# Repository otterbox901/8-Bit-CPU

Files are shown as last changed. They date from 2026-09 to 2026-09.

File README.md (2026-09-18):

# 8-Bit CPU

A CPU built from ~97 individual 74HC-series logic ICs. Custom instruction set, microcoded control unit, and a from-scratch ALU with flag logic, laid out on a 4-layer PCB.

## Status: In progress

- [x] Instruction set architecture (11 instructions, custom encoding)
- [x] ALU design — adder/subtractor, bitwise AND/OR, Z/C/N flag generation
- [x] Register file (4 general-purpose registers) and microcoded control-ROM addressing scheme
- [x] PCB component placement — 97 ICs, board outline drawn (173.5 mm × 115.5 mm, 4-layer)
- [x] Microcode ROM generator — Python script producing control-ROM contents from the ISA/microcode design, checked against the control-unit addressing scheme
- [x] Emulator — Python simulator + assembler that executes `microcode_table.csv` directly, with the full ISA exercised by a bundled test program
- [x] Control unit — the schematic's control-ROM addressing, register-file/ALU
      enable logic, and memory control signals are now actually wired
- [x] PCB routing — fully autorouted (4-layer, 755 nets, 0 DRC errors)
- [ ] Power input connector + regulator (not yet designed — see Known Issues)
- [ ] HLT (clock/sequencer halt) — control-ROM signal exists but isn't wired
      to anything yet
- [ ] Burn control ROM onto physical EEPROMs and hardware bring-up

## Overview

| | |
|---|---|
| Data path | 8-bit |
| Registers | 4 general-purpose (R0–R3), plus PC, MAR, IR, and internal ALU staging registers |
| Control unit | Microcoded — control ROM addressed by opcode, execution step, and ALU status flags (no hardwired branch/decision logic) |
| ALU | Add, subtract (two's complement), AND, OR — with Zero, Carry, and Negative flags |
| Memory | Harvard-style — separate address space for program storage (EEPROM) and data storage (SRAM) |
| Clock target | 1–4 MHz |
| Logic family | 74HC/74LS discrete logic |
| IC count | ~97 |
| Board | 4-layer, 1.6 mm, 173.5 mm × 115.5 mm |

## Instruction Set

| Opcode | Mnemonic | Format | Operation |
|---|---|---|---|
| `0000` | `NOP` | — | No operation |
| `0001` | `LOAD Rd, addr` | Address (3 bytes) | Rd ← MEM[addr] |
| `0010` | `STORE Rd, addr` | Address (3 bytes) | MEM[addr] ← Rd |
| `0011` | `ADD Rd, Rs` | Reg-reg (1 byte) | Rd ← Rd + Rs |
| `0100` | `SUB Rd, Rs` | Reg-reg (1 byte) | Rd ← Rd − Rs |
| `0101` | `JMP addr` | Address (3 bytes) | PC ← addr |
| `0110` | `JZ addr` | Address (3 bytes) | PC ← addr if Zero flag set |
| `0111` | `JC addr` | Address (3 bytes) | PC ← addr if Carry flag set |
| `1000` | `MOV Rd, Rs` | Reg-reg (1 byte) | Rd ← Rs |
| `1001` | `AND Rd, Rs` | Reg-reg (1 byte) | Rd ← Rd AND Rs |
| `1010` | `OR Rd, Rs` | Reg-reg (1 byte) | Rd ← Rd OR Rs |
| `1111` | `HLT` | — | Stop the clock |

Opcodes `1011`–`1110` are reserved for future extension (e.g. a stack pointer with `CALL`/`RET`, or additional ALU operations). Currently they fetch and decode as a no-op.

Instructions are encoded as either one byte (reg-reg) or three bytes (address):

| Format | Byte 0 | Byte 1 | Byte 2 |
|---|---|---|---|
| Reg-reg | `[opcode:4][Rd:2][Rs:2]` | — | — |
| Address | `[opcode:4][Rd:2][--:2]` | addr low | addr high |

The 3-bit step counter cycles 0–7 (wrapping); step 0 is always the fetch (`IROM_OUT` + `IR_IN` + `PC_INC`), steps 1–3 execute the operand/operation, and any trailing steps are no-ops. Conditional jumps are resolved entirely by the control ROM's addressing (the flag bits are part of the ROM address), with no separate comparator logic needed.

## Control ROM

The control ROM is generated rather than hand-populated. A Python script (`microcode_rom_gen.py`) walks every `(opcode, step, Z, C)` combination — a 9-bit, 512-word address space, and derives the 20-bit control word for each from the microcode step tables for each instruction. The control word is split across three 28C256 EEPROMs (8 + 8 + 4 bits), and the script emits both a human-readable CSV (`microcode_table.csv`) and three raw 32 KB binary chip images (`rom1.bin`, `rom2.bin`, `rom3.bin`) ready to burn, with unused upper addresses zero-padded to an all-signals-off state.

## Emulator

`emulator.py` is a cycle-accurate Python model of the CPU driven entirely by the generated control ROM. It arbitrates the 8-bit bus, latches registers and flags per the microcode control signals, and assembles + runs programs, so it can be used to develop and verify software before the hardware comes up.

### Usage

```bash
# Generate the control ROM table first (run from ROM/)
python3 microcode_rom_gen.py

# Run the full instruction-set test program (7/7 checks pass)
python3 emulator.py test_program.asm

# Run the bundled default test (no file argument)
python3 emulator.py

# Per-micro-step trace of bus, registers, and control signals
python3 emulator.py test_program.asm --trace-micro

# Quiet mode — suppress trace, show results only
python3 emulator.py -q test_program.asm
```

The built-in two-pass assembler understands the instruction mnemonics, labels, hex/decimal numbers, `.byte` (program ROM data) and `.ram addr, val` (pre-loads the data SRAM) directives. `test_program.asm` exercises every instruction — LOAD, STORE, ADD, SUB, AND, OR, MOV, NOP, JMP, JZ, JC, HLT — and auto-verifies the resulting data RAM contents against expected values.

## Repo Contents

```
8-Bit-CPU/
├── 8-bit cpu.kicad_sch     KiCad schematic (single flat sheet)
├── 8-bit cpu.kicad_pcb     KiCad PCB layout (routed, 0 DRC errors)
├── microcode_rom_gen.py    Control ROM generator (opcode/step/flags → EEPROM images)
├── emulator.py             Microcode-driven CPU emulator + assembler
├── test_program.asm        Full instruction-set test for the emulator
└── README.md
```

## Known Issues

- **No power input connector or regulator.** All 63 live ICs now share a
  single, correctly-named `+5V` net, but nothing in the schematic actually
  sources it — there's no barrel jack/header and no regulator IC modeled.
  This needs to be designed and added before the board can be powered.
- **HLT isn't wired to anything.** The control ROM correctly asserts the
  `HLT` signal per the microcode, but no hardware currently reads it (no
  clock-gating or sequencer-halt logic exists). Without it, a running CPU
  won't literally stop on `HLT` — it'll keep re-fetching the same
  instruction harmlessly forever rather than actually halting.
- **Cosmetic-only DRC/ERC output remains**: ~55 silkscreen text/outline
  overlaps among tightly-packed passives, and footprint-library-name
  mismatches (PCB footprints reference a `fasteda` library not present in
  every environment — the footprint geometry is embedded in the file
  regardless, so this doesn't affect fabrication).
- None of this has been verified against real hardware yet — see Roadmap.

## Roadmap

1. Design and add a power input connector + regulator
2. Wire HLT to a sequencer-halt/clock-gate
3. Burn the generated control ROM contents onto the EEPROMs
4. Bring-up and testing
5. Print and test on physical hardware

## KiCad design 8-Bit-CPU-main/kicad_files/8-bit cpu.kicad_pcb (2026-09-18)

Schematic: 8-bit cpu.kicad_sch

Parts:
C1, C2, C3, C4, C5, C6, C7, C8, C9, C10, C11, C12, C13, C14, C15, C16, C17, C18, C19, C20, C21, C22, C23, C24, C25, C26, C27, C28, C29, C30, C31, C32: 100nF; C0805
R1: 10k; R0805
SW1: HX 3X4X2-2P-1.6N TACTILE SWITCH; KEY-SMD_L4.0-W3.0-LS4.9-1; MPN HX 3x4x2-2P-1.6N TACTILE SWITCH; LCSC C49234124
U1, U2, U3, U4, U32, U33, U34, U35, U44, U45, U46, U47, U48, U49, U50, U51, U55, U56: 74HC173D,653; SOP-16_L10.0-W3.9-P1.27-LS6.0-BL; MPN 74HC173D,653; LCSC C546652
U5, U6: CD74HC283M96; SOIC-16_L9.9-W3.9-P1.27-LS6.0-BL; MPN CD74HC283M96; LCSC C543032; not fitted
U7, U8: SN74HC86DR; SOIC-14_L8.7-W3.9-P1.27-LS6.0-BL; MPN SN74HC86DR; LCSC C6763
U9, U10, U11, U12, U38, U39, U40, U41: 74HC153D,653; SOIC-16_L9.9-W3.9-P1.27-LS6.0-BL; MPN 74HC153D,653; LCSC C53334
U13: 74HC245D,653; SOIC-20_L13.0-W7.6-P1.27-LS10.3-BL; MPN 74HC245D,653; LCSC C5625; not fitted
U14, U15: 74HC08D,653; SOIC-14_L8.7-W3.9-P1.27-LS6.0-BL; MPN 74HC08D,653; LCSC C5593
U16, U17, U18, U19: 74HC32D,653; SOIC-14_L8.7-W3.9-P1.27-LS6.0-BL; MPN 74HC32D,653; LCSC C5632
U20: 74HC04D,653; SOIC-14_L8.7-W3.9-P1.27-LS6.0-BL; MPN 74HC04D,653; LCSC C5590
U21: 74HC173D,653; SOP-16_L10.0-W3.9-P1.27-LS6.0-BL; MPN 74HC173D,653; LCSC C546652; not fitted
U22, U23, U24: AT28C256-15SU; SOIC-28_L17.9-W7.6-P1.27-LS10.4-BL; MPN AT28C256-15SU; LCSC C1349121; not fitted
U25, U52, U53, U54: SN74HC161DR; SOIC-16_L9.9-W3.9-P1.27-LS6.0-BL; MPN SN74HC161DR; LCSC C6824
U26, U27, U28, U29, U30: SN74HC161DR; SOIC-16_L9.9-W3.9-P1.27-LS6.0-BL; MPN SN74HC161DR; LCSC C6824; not fitted
U31: AT28C64B-15PU; DIP-28_L37.0-W13.8-P2.54-LS15.8-BL; MPN AT28C64B-15PU; LCSC C41982; not fitted
U36, U37: CD74HC283M96; SOIC-16_L9.9-W3.9-P1.27-LS6.0-BL; MPN CD74HC283M96; LCSC C543032
U42: 74HC245D,653; SOIC-20_L13.0-W7.6-P1.27-LS10.3-BL; MPN 74HC245D,653; LCSC C5625
U43: 74HC139D,653; SOIC-16_L9.9-W3.9-P1.27-LS6.0-BL; MPN 74HC139D,653; LCSC C5603
U57, U58, U59: AT28C256-15SU; SOIC-28_L17.9-W7.6-P1.27-LS10.4-BL; MPN AT28C256-15SU; LCSC C1349121
U60: AT28C64B-15PU; DIP-28_L37.0-W13.8-P2.54-LS15.8-BL; MPN AT28C64B-15PU; LCSC C41982
U61: HM6116LP-4; DIP-24_W15.24mm_P2.54mm; MPN HM6116LP-4
U62: OT70501MJBA4SL; OSC-SMD_4P-L7.0-W5.0-BL-2; MPN OT70501MJBA4SL; LCSC C2831414
U63: SN74HC14DR; SOIC-14_L8.7-W3.9-P1.27-LS6.0-BL; MPN SN74HC14DR; LCSC C6820

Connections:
+5V: C1.1, C2.1, C3.1, C4.1, C5.1, C6.1, C7.1, C8.1, C9.1, C10.1, C11.1, C12.1, C13.1, C14.1, C15.1, C16.1, C17.1, C18.1, C19.1, C20.1, C21.1, C22.1, C23.1, C24.1, C25.1, C26.1, C27.1, C28.1, C29.1, C30.1, C31.1, C32.1, R1.1, U1.16 (VCC), U2.16 (VCC), U3.16 (VCC), U4.16 (VCC), U5.16 (VCC), U6.16 (VCC), U7.14 (VCC), U8.14 (VCC), U9.16 (VCC), U10.6 (1I0), U10.10 (2I0), U10.16 (VCC), U11.6 (1I0), U11.10 (2I0), U11.16 (VCC), U12.6 (1I0), U12.10 (2I0), U12.16 (VCC), U13.20 (VCC), U14.14 (VCC), U15.14 (VCC), U16.14 (VCC), U17.14 (VCC), U18.14 (VCC), U19.14 (VCC), U20.14 (VCC), U21.16 (VCC), U22.28 (VCC), U23.27 (~WE), U23.28 (VCC), U24.28 (VCC), U25.7 (ENP), U25.9 (~LOAD), U25.10 (ENT), U25.16 (VCC), U26.16 (VCC), U27.16 (VCC), U28.16 (VCC), U29.16 (VCC), U30.16 (VCC), U31.28 (VCC), U32.16 (VCC), U33.16 (VCC), U34.16 (VCC), U35.16 (VCC), U36.16 (VCC), U37.16 (VCC), U38.16 (VCC), U39.16 (VCC), U40.16 (VCC), U41.16 (VCC), U42.20 (VCC), U43.16 (VCC), U44.16 (VCC), U45.16 (VCC), U46.16 (VCC), U47.16 (VCC), U48.16 (VCC), U49.16 (VCC), U50.16 (VCC), U51.16 (VCC), U52.16 (VCC), U53.16 (VCC), U54.16 (VCC), U55.16 (VCC), U56.16 (VCC), U57.27 (~WE), U57.28 (VCC), U58.27 (~WE), U58.28 (VCC), U59.27 (~WE), U59.28 (VCC), U60.27 (~WE), U60.28 (VCC), U61.24 (VCC), U62.1 (Tri-state), U62.4 (VDD), U63.14 (VCC)
A0: U23.10 (A0), U31.10 (A0)
A1: U23.9 (A1), U31.9 (A1)
A2: U23.8 (A2), U31.8 (A2)
A3: U23.7 (A3), U31.7 (A3)
A4: U23.6 (A4), U31.6 (A4)
A5: U23.5 (A5), U31.5 (A5)
A6: U23.4 (A6), U31.4 (A6)
A7: U23.3 (A7), U31.3 (A7)
A8: U23.25 (A8), U31.25 (A8)
A9: U23.24 (A9), U31.24 (A9)
A10: U23.21 (A10), U31.21 (A10)
A11: U23.23 (A11), U31.23 (A11)
A12: U23.2 (A12), U31.2 (A12)
A13_ADDR: U23.26 (A13)
A14: U23.1 (A14)
ALU_A0: U14.1 (1A), U16.1 (1A), U32.3 (Q0), U36.5 (A0)
ALU_A0_2: U5.5 (A0)
ALU_A1: U14.4 (2A), U16.4 (2A), U32.4 (Q1), U36.3 (A1)
ALU_A1_2: U5.3 (A1)
ALU_A2: U14.9 (3A), U16.9 (3A), U32.5 (Q2), U36.14 (A2)
ALU_A2_2: U5.14 (A2)
ALU_A3: U14.12 (4A), U16.12 (4A), U32.6 (Q3), U36.12 (A3)
ALU_A3_2: U5.12 (A3)
ALU_A4: U15.1 (1A), U17.1 (1A), U34.3 (Q0), U37.5 (A0)
ALU_A4_2: U6.5 (A0)
ALU_A5: U15.4 (2A), U17.4 (2A), U34.4 (Q1), U37.14 (A2)
ALU_A5_2: U6.14 (A2)
ALU_A6: U15.9 (3A), U17.9 (3A), U34.5 (Q2), U37.3 (A1)
ALU_A6_2: U6.3 (A1)
ALU_A7: U15.12 (4A), U17.12 (4A), U34.6 (Q3), U37.12 (A3)
ALU_A7_2: U6.12 (A3)
ALU_AND0: U14.3 (1Y), U38.5 (1I1)
ALU_AND1: U14.6 (2Y), U38.11 (2I1)
ALU_AND2: U14.8 (3Y), U39.5 (1I1)
ALU_AND3: U14.11 (4Y), U39.11 (2I1)
ALU_AND4: U15.3 (1Y), U40.5 (1I1)
ALU_AND5: U15.6 (2Y), U40.11 (2I1)
ALU_AND6: U15.8 (3Y), U41.5 (1I1)
ALU_AND7: U15.11 (4Y), U41.11 (2I1)
ALU_B0: U7.3 (1Y), U14.2 (1B), U16.2 (1B), U36.6 (B0), U38.3 (1I3)
ALU_B0_2: U5.6 (B0)
ALU_B1: U7.6 (2Y), U14.5 (2B), U16.5 (2B), U36.2 (B1), U38.13 (2I3)
ALU_B1_2: U5.2 (B1)
ALU_B2: U7.8 (3Y), U14.10 (3B), U16.10 (3B), U36.15 (B2), U39.3 (1I3)
ALU_B2_2: U5.15 (B2)
ALU_B3: U7.11 (4Y), U14.13 (4B), U16.13 (4B), U36.11 (B3), U39.13 (2I3)
ALU_B3_2: U5.11 (B3)
ALU_B4: U8.3 (1Y), U15.2 (1B), U17.2 (1B), U37.6 (B0), U40.3 (1I3)
ALU_B4_2: U6.6 (B0)
ALU_B5: U8.6 (2Y), U15.5 (2B), U17.5 (2B), U37.15 (B2), U40.13 (2I3)
ALU_B5_2: U6.15 (B2)
ALU_B6: U8.8 (3Y), U15.10 (3B), U17.10 (3B), U37.2 (B1), U41.3 (1I3)
ALU_B6_2: U6.2 (B1)
ALU_B7: U8.11 (4Y), U15.13 (4B), U17.13 (4B), U37.11 (B3), U41.13 (2I3)
ALU_B7_2: U6.11 (B3)
ALU_B_RAW0: U7.1 (1A), U33.3 (Q0)
ALU_B_RAW1: U7.4 (2A), U33.4 (Q1)
ALU_B_RAW2: U7.9 (3A), U33.5 (Q2)
ALU_B_RAW3: U7.12 (4A), U33.6 (Q3)
ALU_B_RAW4: U8.1 (1A), U35.3 (Q0)
ALU_B_RAW5: U8.4 (2A), U35.4 (Q1)
ALU_B_RAW6: U8.9 (3A), U35.5 (Q2)
ALU_B_RAW7: U8.12 (4A), U35.6 (Q3)
ALU_CARRY_MID: U36.9 (COUT), U37.7 (CIN)
ALU_MUX_OUT0: U18.1 (1A), U38.7 (1Y), U42.18 (B0)
ALU_MUX_OUT1: U18.2 (1B), U38.9 (2Y), U42.17 (B1)
ALU_MUX_OUT2: U18.4 (2A), U39.7 (1Y), U42.16 (B2)
ALU_MUX_OUT3: U18.5 (2B), U39.9 (2Y), U42.15 (B3)
ALU_MUX_OUT4: U18.9 (3A), U40.7 (1Y), U42.14 (B4)
ALU_MUX_OUT5: U18.10 (3B), U40.9 (2Y), U42.13 (B5)
ALU_MUX_OUT6: U18.12 (4A), U41.7 (1Y), U42.12 (B6)
ALU_MUX_OUT7: U18.13 (4B), U41.9 (2Y), U42.11 (B7)
ALU_OR0: U16.3 (1Y), U38.4 (1I2)
ALU_OR1: U16.6 (2Y), U38.12 (2I2)
ALU_OR2: U16.8 (3Y), U39.4 (1I2)
ALU_OR3: U16.11 (4Y), U39.12 (2I2)
ALU_OR4: U17.3 (1Y), U40.4 (1I2)
ALU_OR5: U17.6 (2Y), U40.12 (2I2)
ALU_OR6: U17.8 (3Y), U41.4 (1I2)
ALU_OR7: U17.11 (4Y), U41.12 (2I2)
ALU_S0: U36.4 (S0), U38.6 (1I0)
ALU_S1: U36.1 (S1), U38.10 (2I0)
ALU_S2: U36.13 (S2), U39.6 (1I0)
ALU_S3: U36.10 (S3), U39.10 (2I0)
ALU_S4: U37.4 (S0), U40.6 (1I0)
ALU_S5: U37.1 (S1), U40.10 (2I0)
ALU_S6: U37.13 (S2), U41.6 (1I0)
ALU_S7: U37.10 (S3), U41.10 (2I0)
ALU_SEL0: U38.14 (S0), U39.14 (S0), U40.14 (S0), U41.14 (S0), U58.17 (I/O5)
ALU_SEL1: U38.2 (S1), U39.2 (S1), U40.2 (S1), U41.2 (S1), U58.18 (I/O6)
A_IN: U32.9 (#E1), U32.10 (#E2), U34.9 (#E1), U34.10 (#E2), U58.15 (I/O3)
C: U4.4 (Q1), U57.10 (A0), U58.10 (A0), U59.10 (A0)
CIN: U5.9 (COUT), U6.7 (CIN)
CLK: U1.7 (CP), U2.7 (CP), U3.7 (CP), U4.7 (CP), U25.2 (CLK), U32.7 (CP), U33.7 (CP), U34.7 (CP), U35.7 (CP), U44.7 (CP), U45.7 (CP), U46.7 (CP), U47.7 (CP), U48.7 (CP), U49.7 (CP), U50.7 (CP), U51.7 (CP), U52.2 (CLK), U53.2 (CLK), U54.2 (CLK), U55.7 (CP), U56.7 (CP), U62.3 (OUTPUT)
CLK_2: U21.7 (CP), U26.2 (CLK), U27.2 (CLK), U28.2 (CLK), U29.2 (CLK), U30.2 (CLK)
C_COMPUTED: U4.13 (D1), U37.9 (COUT)
D0: U23.11 (I/O0), U31.11 (IO0)
D1: U23.12 (I/O1), U31.12 (IO1)
D2: U23.13 (I/O2), U31.13 (IO2)
D3: U23.15 (I/O3), U31.15 (IO3)
D4: U23.16 (I/O4), U31.16 (IO4), U59.16 (I/O4)
D5: U23.17 (I/O5), U31.17 (IO5), U59.17 (I/O5)
D6: U23.18 (I/O6), U31.18 (IO6), U59.18 (I/O6)
D7: U23.19 (I/O7), U31.19 (IO7), U59.19 (I/O7)
DBUS0: U1.14 (D0), U3.14 (D0), U32.14 (D0), U33.14 (D0), U42.2 (A0), U44.3 (Q0), U44.14 (D0), U46.3 (Q0), U46.14 (D0), U48.3 (Q0), U48.14 (D0), U50.3 (Q0), U50.14 (D0), U55.14 (D0), U60.11 (IO0), U61.9 (I/O0)
DBUS0_2: U13.2 (A0), U21.14 (D0)
DBUS1: U1.13 (D1), U3.13 (D1), U32.13 (D1), U33.13 (D1), U42.3 (A1), U44.4 (Q1), U44.13 (D1), U46.4 (Q1), U46.13 (D1), U48.4 (Q1), U48.13 (D1), U50.4 (Q1), U50.13 (D1), U55.13 (D1), U60.12 (IO1), U61.10 (I/O1)
DBUS1_2: U13.3 (A1), U21.13 (D1)
DBUS2: U1.12 (D2), U3.12 (D2), U32.12 (D2), U33.12 (D2), U42.4 (A2), U44.5 (Q2), U44.12 (D2), U46.5 (Q2), U46.12 (D2), U48.5 (Q2), U48.12 (D2), U50.5 (Q2), U50.12 (D2), U55.12 (D2), U60.13 (IO2), U61.11 (I/O2)
DBUS2_2: U13.4 (A2), U21.12 (D2)
DBUS3: U1.11 (D3), U3.11 (D3), U32.11 (D3), U33.11 (D3), U42.5 (A3), U44.6 (Q3), U44.11 (D3), U46.6 (Q3), U46.11 (D3), U48.6 (Q3), U48.11 (D3), U50.6 (Q3), U50.11 (D3), U55.11 (D3), U60.15 (IO3), U61.13 (I/O3)
DBUS3_2: U13.5 (A3), U21.11 (D3)
DBUS4: U2.14 (D0), U34.14 (D0), U35.14 (D0), U42.6 (A4), U45.3 (Q0), U45.14 (D0), U47.3 (Q0), U47.14 (D0), U49.3 (Q0), U49.14 (D0), U51.3 (Q0), U51.14 (D0), U56.14 (D0), U60.16 (IO4), U61.14 (I/O4)
DBUS5: U2.13 (D1), U34.13 (D1), U35.13 (D1), U42.7 (A5), U45.4 (Q1), U45.13 (D1), U47.4 (Q1), U47.13 (D1), U49.4 (Q1), U49.13 (D1), U51.4 (Q1), U51.13 (D1), U56.13 (D1), U60.17 (IO5), U61.15 (I/O5)
DBUS6: U2.12 (D2), U34.12 (D2), U35.12 (D2), U42.8 (A6), U45.5 (Q2), U45.12 (D2), U47.5 (Q2), U47.12 (D2), U49.5 (Q2), U49.12 (D2), U51.5 (Q2), U51.12 (D2), U56.12 (D2), U60.18 (IO6), U61.16 (I/O6)
DBUS7: U2.11 (D3), U34.11 (D3), U35.11 (D3), U42.9 (A7), U45.6 (Q3), U45.11 (D3), U47.6 (Q3), U47.11 (D3), U49.6 (Q3), U49.11 (D3), U51.6 (Q3), U51.11 (D3), U56.11 (D3), U60.19 (IO7), U61.17 (I/O7)
EO: U12.14 (S0), U59.11 (I/O0)
EO_N: U12.7 (1Y), U12.9 (2Y), U42.19 (~OE)
FI_C: U19.13 (4B), U59.13 (I/O2)
FI_LATCH_N: U4.9 (#E1), U4.10 (#E2), U11.7 (1Y), U11.9 (2Y)
FI_OR: U11.14 (S0), U19.11 (4Y)
FI_ZN: U19.12 (4A), U59.12 (I/O1)
HLT: U59.15 (I/O3)
IROM_OUT: U20.1 (1A), U57.11 (I/O0)
IROM_OUT_N: U20.2 (1Y), U60.22 (~OE)
IR_IN: U55.9 (#E1), U55.10 (#E2), U56.9 (#E1), U56.10 (#E2), U57.15 (I/O3)
IR_RD0: U9.6 (1I0), U55.5 (Q2)
IR_RD1: U9.10 (2I0), U55.6 (Q3)
IR_RS0: U9.5 (1I1), U55.3 (Q0)
IR_RS1: U9.11 (2I1), U55.4 (Q1)
MARH0: U3.3 (Q0), U54.3 (A), U61.23 (A8)
MARH1: U3.4 (Q1), U54.4 (B), U61.22 (A9)
MARH2: U3.5 (Q2), U54.5 (C), U61.19 (A10)
MARH3: U3.6 (Q3), U54.6 (D)
MARL0: U1.3 (Q0), U52.3 (A), U61.8 (A0)
MARL1: U1.4 (Q1), U52.4 (B), U61.7 (A1)
MARL2: U1.5 (Q2), U52.5 (C), U61.6 (A2)
MARL3: U1.6 (Q3), U52.6 (D), U61.5 (A3)
MARL4: U2.3 (Q0), U53.3 (A), U61.4 (A4)
MARL5: U2.4 (Q1), U53.4 (B), U61.3 (A5)
MARL6: U2.5 (Q2), U53.5 (C), U61.2 (A6)
MARL7: U2.6 (Q3), U53.6 (D), U61.1 (A7)
MAR_HIGH_IN: U3.9 (#E1), U3.10 (#E2), U57.17 (I/O5)
MAR_LOW_IN: U1.9 (#E1), U1.10 (#E2), U2.9 (#E1), U2.10 (#E2), U57.16 (I/O4)
unnamed: SW1.1, U63.1 (1A)
OE: U23.22 (~OE)
OPCODE0: U56.3 (Q0), U57.5 (A5), U58.5 (A5), U59.5 (A5)
OPCODE1: U56.4 (Q1), U57.4 (A6), U58.4 (A6), U59.4 (A6)
OPCODE2: U56.5 (Q2), U57.3 (A7), U58.3 (A7), U59.3 (A7)
OPCODE3: U56.6 (Q3), U57.25 (A8), U58.25 (A8), U59.25 (A8)
PC0: U52.14 (QA), U60.10 (A0)
PC1: U52.13 (QB), U60.9 (A1)
PC2: U52.12 (QC), U60.8 (A2)
PC3: U52.11 (QD), U60.7 (A3)
PC4: U53.14 (QA), U60.6 (A4)
PC5: U53.13 (QB), U60.5 (A5)
PC6: U53.12 (QC), U60.4 (A6)
PC7: U53.11 (QD), U60.3 (A7)
PC8: U54.14 (QA), U60.25 (A8)
PC9: U54.13 (QB), U60.24 (A9)
PC10: U60.21 (A10)
PC11: U60.23 (A11)
PC_CARRY0: U52.15 (RCO), U53.7 (ENP), U53.10 (ENT)
PC_CARRY1: U53.15 (RCO), U54.7 (ENP), U54.10 (ENT)
PC_INC: U52.7 (ENP), U52.10 (ENT), U57.18 (I/O6)
PC_LOAD: U20.13 (6A), U57.19 (I/O7)
PC_LOAD_N: U20.12 (6Y), U52.9 (~LOAD), U53.9 (~LOAD), U54.9 (~LOAD)
RAM_IN: U20.5 (3A), U57.13 (I/O2)
RAM_IN_N: U20.6 (3Y), U61.21 (WE)
RAM_OUT: U20.3 (2A), U57.12 (I/O1)
RAM_OUT_N: U20.4 (2Y), U61.20 (OE)
REGSEL_Y0: U43.4 (~1Y0), U44.1 (#OE1), U44.9 (#E1), U45.1 (#OE1), U45.9 (#E1)
REGSEL_Y1: U43.5 (~1Y1), U46.1 (#OE1), U46.9 (#E1), U47.1 (#OE1), U47.9 (#E1)
REGSEL_Y2: U43.6 (~1Y2), U48.1 (#OE1), U48.9 (#E1), U49.1 (#OE1), U49.9 (#E1)
REGSEL_Y3: U43.7 (~1Y3), U50.1 (#OE1), U50.9 (#E1), U51.1 (#OE1), U51.9 (#E1)
REG_IN: U20.9 (4A), U58.12 (I/O1)
REG_IN_N: U20.8 (4Y), U44.10 (#E2), U45.10 (#E2), U46.10 (#E2), U47.10 (#E2), U48.10 (#E2), U49.10 (#E2), U50.10 (#E2), U51.10 (#E2)
REG_OUT: U20.11 (5A), U58.13 (I/O2)
REG_OUT_N: U20.10 (5Y), U44.2 (#OE), U45.2 (#OE), U46.2 (#OE), U47.2 (#OE), U48.2 (#OE), U49.2 (#OE), U50.2 (#OE), U51.2 (#OE)
REG_SEL0: U9.7 (1Y), U43.2 (1A0)
REG_SEL1: U9.9 (2Y), U43.3 (1A1)
RESET_N: U25.1 (~CLR), U52.1 (~CLR), U53.1 (~CLR), U54.1 (~CLR), U63.2 (1Y)
ROM_CE: U31.20 (~CE)
ROM_CS: U23.20 (~CE)
ROM_OE: U31.22 (~OE)
ROM_WE: U31.27 (~WE)
RS_SEL: U9.14 (S0), U58.11 (I/O0)
STEP0: U25.14 (QA), U57.8 (A2), U58.8 (A2), U59.8 (A2)
STEP1: U25.13 (QB), U57.7 (A3), U58.7 (A3), U59.7 (A3)
STEP2: U25.12 (QC), U57.6 (A4), U58.6 (A4), U59.6 (A4)
SU: U7.2 (1B), U7.5 (2B), U7.10 (3B), U7.13 (4B), U8.2 (1B), U8.5 (2B), U8.10 (3B), U8.13 (4B), U36.7 (CIN), U58.19 (I/O7)
TEMP_IN: U33.9 (#E1), U33.10 (#E2), U35.9 (#E1), U35.10 (#E2), U58.16 (I/O4)
Z: U4.3 (Q0), U57.9 (A1), U58.9 (A1), U59.9 (A1)
ZT_G1: U18.3 (1Y), U19.1 (1A)
ZT_G2: U18.6 (2Y), U19.2 (1B)
ZT_G3: U18.8 (3Y), U19.4 (2A)
ZT_G4: U18.11 (4Y), U19.5 (2B)
ZT_G5: U19.3 (1Y), U19.9 (3A)
ZT_G6: U19.6 (2Y), U19.10 (3B)
ZT_G7: U10.14 (S0), U19.8 (3Y)
Z_COMPUTED: U4.14 (D0), U10.7 (1Y), U10.9 (2Y)

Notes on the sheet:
Register File (R0-R3)
PROTOFLOW_REGION:eyJpZCI6IjU4ZTk1ZGUwLWQ1NzItNDgwZS1iOGE4LTMwOGQ0NjZiYzUxMCIsIm5hbWUiOiJNaWNyb2NvZGVkIENvbnRyb2wgVW5pdCIsIngxIjoyODk5LjQxNTk5OTk5OTk5OTcsInkxIjo2OTUyLjc3OTk5OTk5OTk5OSwieDIiOjM1NzAuNjA0LCJ5MiI6NzUyMC42MTk5OTk5OTk5OTksImNvbG9yIjo0Mjg1NTA3ODA0LCJkZXNjcmlwdGlvbiI6bnVsbCwiY29tcG9uZW50SW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
ALU & Accumulator
PC & MAR
PROTOFLOW_REGION:eyJpZCI6ImQwOGRlMzg5LTczMzYtNDk4Yy04ODE5LWVmMjRlN2U5MTFmZiIsIm5hbWUiOiJQQyAmIE1BUiIsIngxIjo2ODEuOTQ4MDQ1NDA4OTc3NiwieTEiOjU0ODguOTY3ODgyMjI3OTUzLCJ4MiI6MTY0My41OTg2NTkwOTg1MDM1LCJ5MiI6NTkwMi4xOTI3MDY2MzIyODIsImNvbG9yIjo0Mjg1NTA3ODA0LCJkZXNjcmlwdGlvbiI6bnVsbCwiY29tcG9uZW50SWRzIjpbIj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
Microcoded Control Unit
PROTOFLOW_REGION:eyJpZCI6Ijc0NTk5OWZjLThkMjAtNDZjZi1iOTllLWVmZjEyNDk2OTU4YyIsIm5hbWUiOiJSZWdpc3RlciBGaWxlIChSMC1SMykiLCJ4MSI6Mjg2Ny44NiwieTEiOjM2MzMuMCwieDIiOjM4NDguODM5OTk5OTk5OTk5NywieTIiOjQzMjUuMjk5OTk5OTk5OTk5LCJjb2xvciI6NDI4NTUwNzgwNCwiZGVzY3JpcHRpb24iOm51bGwsImNvbXBvbmVudElkcyI6WyI3NDlmZTUxMi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
PROTOFLOW_REGION:eyJpZCI6IjVkNGIwZmM1LTFhMTAtNDM5ZS04NDNmLWZhNTM1OTEyMjRjNSIsIm5hbWUiOiJJbnN0cnVjdGlvbiBSZWdpc3RlciIsIngxIjo2ODg3LjQ2MDA2NzgzOTc5NjUsInkxIjo1NDI0LjY0MDI1NDM5OTIzNywieDIiOjc1NTYuOTM5NTkyOTYxMjI0LCJ5MiI6NTg2My45NTk5NTc2MDAxMjcsImNvbG9yIjo0Mjg1NTA3ODA0LCJkZXNjcmlwdGlvbiI6bnVsbCwiY29tcG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
Harvard Memory (ROM/RAM)
PROTOFLOW_REGION:eyJpZCI6IjgxODk1M2NkLTIwNDctNGZhOS04OWJjLWY2ZTA4OGU5NjlkOCIsIm5hbWUiOiJJbnN0cnVjdGlvbiBSZWdpc3RlciIsIngxIjo4ODQzLjcwMDA2NzgzOTc5NiwieTEiOjUxMjcuNDYwMjU0Mzk5MjM3LCJ4MiI6OTU0Mi4yOTk1OTI5NjEyMjMsInkyIjo3NjQ3LjAzOTk1NzYwMDEyNywiY29sb3IiOjQyODU1MDc4MDQsImRlc2NyaXB0aW9uIjpudWxsLCJjb21wb2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
Instruction Register
PROTOFLOW_REGION:eyJpZCI6IjUwMTk2OGM1LWJhNDQtNGM0NC1iZjc2LTNjNGEwOTgwY2MwZCIsIm5hbWUiOiJBTFUgJiBBY2N1bXVsYXRvciIsIngxIjoxMzk5LjQyLCJ5MSI6MTIwNC43NiwieDIiOjM1OTEuNjgwMDAwMDAwMDAwMywieTIiOjMwNzAuNTQsImNvbG9yIjo0Mjg1NTA3ODA0LCJkZXNjcmlwdGlvbiI6bnVsbCwiY29tcG9uZW50SWRzIjpbImFiYWQ5NWEwLWFmOTQtNGUxOS1hNG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
PROTOFLOW_REGION:eyJpZCI6ImE2YzI4Y2E5LTZkZjEtNDk1NS1iODRlLTMyMjFmNzJhYzUxMSIsIm5hbWUiOiJBTFUgJiBBY2N1bXVsYXRvciIsIngxIjoxMDg5NS40NDIxNTY2MTAzMjMsInkxIjo3NDUuNTA4NzM3MDgwMDEwMiwieDIiOjExNzMwLjAwOTMxODQ2NDkyNywieTIiOjExNjEuNjQ4NTQzODE5OTk4NCwiY29sb3IiOjQyODU1MDc4MDQsImRlc2NyaXB0aW9uIjpudWxsLCJjb21wb2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
PROTOFLOW_REGION:eyJpZCI6ImY1NGE1ZjVkLTI3MzctNDcwYS1hYWE1LWYzOGVjYjY1ZTQxNiIsIm5hbWUiOiJBTFUgJiBBY2N1bXVsYXRvciIsIngxIjo1Nzc4LjQzOTk5OTk5OTk5OSwieTEiOjEzODIuNTYsIngyIjo3NDE2Ljg2MDAwMDAwMDAwMSwieTIiOjMyNDguMzM5OTk5OTk5OTk5LCJjb2xvciI6NDI4NTUwNzgwNCwiZGVzY3JpcHRpb24iOm51bGwsImNvbXBvbmVudElkcyI6WyJlMT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
PROTOFLOW_REGION:eyJpZCI6IjY5YTFmMGFkLWIxYjItNDAzNy1hN2QzLTY4MjFiODA4MDY5NiIsIm5hbWUiOiJBTFUgJiBBY2N1bXVsYXRvciIsIngxIjo5MjYxLjQ5NiwieTEiOjc5OC4zNjAwMDAwMDAwMDAxLCJ4MiI6OTk0OC4yMjM5OTk5OTk5OTgsInkyIjoxMTUyLjgzOTk5OTk5OTk5OTcsImNvbG9yIjo0Mjg1NTA3ODA0LCJkZXNjcmlwdGlvbiI6bnVsbCwiY29tcG9uZW50SWRzIjpbIj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
PROTOFLOW_REGION:eyJpZCI6ImM1ZWZlYzMwLTgwMmQtNDFiYy1iMjNmLTBmMzZiY2YyMzBiZiIsIm5hbWUiOiJQQyAmIE1BUiIsIngxIjo5ODEuNjkxOTk5OTk5OTk5MSwieTEiOjQzMDguMTYsIngyIjoxMjMwMy4wOTk5OTk5OTk5OTksInkyIjo3ODYzLjAzOTk5OTk5OTk5OSwiY29sb3IiOjQyODU1MDc4MDQsImRlc2NyaXB0aW9uIjpudWxsLCJjb21wb25lbnRJZHMiOlsiOTM2Y2YyNDMtMT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
PROTOFLOW_REGION:eyJpZCI6ImYzOGFlNmUzLTgwYzktNDg3Ny04YTE1LTFjMGM4ZDU0ODU0YSIsIm5hbWUiOiJBTFUgJiBBY2N1bXVsYXRvciIsIngxIjoxNjY1LjAzOTk5OTk5OTk5OTUsInkxIjozMDgyLjMwODczNzA4MDAwOTUsIngyIjo0MDQyLjY1OTk5OTk5OTk5OTQsInkyIjozOTQyLjk0ODU0MzgxOTk5NywiY29sb3IiOjQyODU1MDc4MDQsImRlc2NyaXB0aW9uIjpudWxsLCJjb21wb2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
PROTOFLOW_REGION:eyJpZCI6ImYwNzBlMWE5LWNlMWYtNGMyOC04OGFiLTJhNWIyNzhlZmM4NiIsIm5hbWUiOiJSZWdpc3RlciBGaWxlIChSMC1SMykiLCJ4MSI6NzIwNy4yNTU5OTk5OTk5OTksInkxIjoyMjk2Ljk2LCJ4MiI6ODMwNS4xNjQsInkyIjozMDk1LjkzOTk5OTk5OTk5ODcsImNvbG9yIjo0Mjg1NTA3ODA0LCJkZXNjcmlwdGlvbiI6bnVsbCwiY29tcG9uZW50SWRzIjpbIjg1MTRiMT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
PROTOFLOW_REGION:eyJpZCI6ImQwNmEyMDI4LTdiNDgtNDUxNi1hNGFiLTVmMzEzM2Y0Y2ExNSIsIm5hbWUiOiJBTFUgJiBBY2N1bXVsYXRvciIsIngxIjozNzE2LjgxOTk5OTk5OTk5OTcsInkxIjoxMjA0Ljc2LCJ4MiI6NTc3OC4xNzk5OTk5OTk5OTg1LCJ5MiI6MzA3MC41NCwiY29sb3IiOjQyODU1MDc4MDQsImRlc2NyaXB0aW9uIjpudWxsLCJjb21wb25lbnRJZHMiOlsiZjUyYjZhMWUtMj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
PROTOFLOW_REGION:eyJpZCI6IjA1MzM3YmE4LTVmNjItNGNmYi04MjliLWY0OWIwY2YxMTU5MyIsIm5hbWUiOiJSZWdpc3RlciBGaWxlIChSMC1SMykiLCJ4MSI6MTEwMDIuMjYwMDY3ODM5Nzk4LCJ5MSI6MjI4Ny43NDAyNTQzOTkyMzY2LCJ4MiI6MTE2NzEuNzM5NTkyOTYxMjIxLCJ5MiI6MjcyNy4wNTk5NTc2MDAxMjcsImNvbG9yIjo0Mjg1NTA3ODA0LCJkZXNjcmlwdGlvbiI6bnVsbCwiY2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
PROTOFLOW_REGION:eyJpZCI6ImFlMDAwMWJlLTI4MTItNDBlZC1iNWNmLWU3NWY5Y2IzMGYyNCIsIm5hbWUiOiJNaWNyb2NvZGVkIENvbnRyb2wgVW5pdCIsIngxIjoxMDg0OS42MTYsInkxIjo1MzkwLjY3OTk5OTk5OTk5OSwieDIiOjExNTIwLjgwMzk5OTk5OTk5OCwieTIiOjU5NTguNTE5OTk5OTk5OTk5NSwiY29sb3IiOjQyODU1MDc4MDQsImRlc2NyaXB0aW9uIjpudWxsLCJjb21wb25lbn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
PROTOFLOW_REGION:eyJpZCI6Ijg3YWQxMjgyLWNjYzAtNDIwYS04NDJiLTIxMDcwOGU0NDUxNiIsIm5hbWUiOiJSZWdpc3RlciBGaWxlIChSMC1SMykiLCJ4MSI6NDA3NC44Nzk5OTk5OTk5OTk3LCJ5MSI6MzU0MS41NTk5OTk5OTk5OTk1LCJ4MiI6ODM1Mi43MiwieTIiOjU0MDcuMzQsImNvbG9yIjo0Mjg1NTA3ODA0LCJkZXNjcmlwdGlvbiI6bnVsbCwiY29tcG9uZW50SWRzIjpbImE0ZTZmZj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
PROTOFLOW_REGION:eyJpZCI6Ijg3YjU1NjIxLWJhODgtNDBlYy05MWQyLWRlYTY3ZmE5ZTg0ZCIsIm5hbWUiOiJSZWdpc3RlciBGaWxlIChSMC1SMykiLCJ4MSI6ODg2OC42NjAwNjc4Mzk3OTUsInkxIjozODQ5Ljg0MDI1NDM5OTIzNiwieDIiOjk1MzguMTM5NTkyOTYxMjIzLCJ5MiI6NDI4OS4xNTk5NTc2MDAxMjYsImNvbG9yIjo0Mjg1NTA3ODA0LCJkZXNjcmlwdGlvbiI6bnVsbCwiY29tcG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
PROTOFLOW_REGION:eyJpZCI6ImUzOTU4MWMxLTA1MGMtNDlmOC05MzM5LTkwOTQyYzM4MGRhZSIsIm5hbWUiOiJBTFUgJiBBY2N1bXVsYXRvciIsIngxIjo1NTguNDYyOTEyMzYwMDAzMiwieTEiOjMwODIuMzA4NzM3MDgwMDEwNCwieDIiOjE1MjUuNDIyNTI1ODM5OTgsInkyIjozOTQyLjk0ODU0MzgxOTk5OCwiY29sb3IiOjQyODU1MDc4MDQsImRlc2NyaXB0aW9uIjpudWxsLCJjb21wb25lbn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
PROTOFLOW_REGION:eyJpZCI6IjI0Yjk0NjM3LTllN2EtNGIxYy1hMWNlLWJjOTQzMmY4ODQ5MyIsIm5hbWUiOiJBTFUgJiBBY2N1bXVsYXRvciIsIngxIjo3MzQ2Ljk1NiwieTEiOjQ5NS43NjAwNDIzOTk4NzI3LCJ4MiI6ODI2Ny4wNjM5OTk5OTk5OTgsInkyIjoxMjc5LjMzOTc0NTYwMDc2MywiY29sb3IiOjQyODU1MDc4MDQsImRlc2NyaXB0aW9uIjpudWxsLCJjb21wb25lbnRJZHMiOlsiMG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
PROTOFLOW_REGION:eyJpZCI6ImMxYjY3ZDc2LTdhZTgtNGE0MC1hYzdjLTE3NTYxNzU1NDQxNyIsIm5hbWUiOiJSZWdpc3RlciBGaWxlIChSMC1SMykiLCJ4MSI6OTMwMC40NjAwNjc4Mzk3OTYsInkxIjoyMjg3Ljc0MDI1NDM5OTIzNjYsIngyIjo5OTY5LjkzOTU5Mjk2MTIyLCJ5MiI6MjcyNy4wNTk5NTc2MDAxMjcsImNvbG9yIjo0Mjg1NTA3ODA0LCJkZXNjcmlwdGlvbiI6bnVsbCwiY29tcG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
PROTOFLOW_REGION:eyJpZCI6ImEyYzkzMjg1LTRiMDUtNGUwOS04NmU0LTRiZjkwMGI0OWM0ZSIsIm5hbWUiOiJNaWNyb2NvZGVkIENvbnRyb2wgVW5pdCIsIngxIjo5MDUuNTE1OTk5OTk5OTk5OCwieTEiOjY5NTIuNzc5OTk5OTk5OTk5LCJ4MiI6MTU3Ni43MDQsInkyIjo3NTIwLjYxOTk5OTk5OTk5OSwiY29sb3IiOjQyODU1MDc4MDQsImRlc2NyaXB0aW9uIjpudWxsLCJjb21wb25lbnRJZH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
PROTOFLOW_REGION:eyJpZCI6ImQ0OWIxNWI2LWQ5OGUtNGYyYS1iNWJkLTdmMWU4NTJiYWIyYyIsIm5hbWUiOiJSZWdpc3RlciBGaWxlIChSMC1SMykiLCJ4MSI6NDU0My4wNDAwNjc4Mzk3OTYsInkxIjozNjMzLjAsIngyIjo1NjIxLjQ1OTU5Mjk2MTIyMiwieTIiOjQzMjUuMjk5OTk5OTk5OTk5LCJjb2xvciI6NDI4NTUwNzgwNCwiZGVzY3JpcHRpb24iOm51bGwsImNvbXBvbmVudElkcyI6Wy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
PROTOFLOW_REGION:eyJpZCI6ImE2OGJjMjA3LTU1ZmYtNDZkMC04NmZlLTA5OGI0YTBjYzZhZCIsIm5hbWUiOiJSZWdpc3RlciBGaWxlIChSMC1SMykiLCJ4MSI6NTQuMTQwMDAwMDAwMDAwMzMsInkxIjozNDUwLjExOTk5OTk5OTk5OSwieDIiOjQyODQuNjU5OTk5OTk5OTk5LCJ5MiI6NTQyMi41OCwiY29sb3IiOjQyODU1MDc4MDQsImRlc2NyaXB0aW9uIjpudWxsLCJjb21wb25lbnRJZHMiOl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
PROTOFLOW_REGION:eyJpZCI6IjE4NWYyMGNmLTUyYTgtNGM1Ny04NGU5LTA0Y2M4ZWY3MjE5YyIsIm5hbWUiOiJIYXJ2YXJkIE1lbW9yeSAoUk9NL1JBTSkiLCJ4MSI6NDg5OC4zOTU5OTk5OTk5OTksInkxIjo2OTUyLjc4LCJ4MiI6NTUzNC4wMjM5OTk5OTk5OTksInkyIjo3NTIwLjYyLCJjb2xvciI6NDI4NTUwNzgwNCwiZGVzY3JpcHRpb24iOm51bGwsImNvbXBvbmVudElkcyI6WyIxZjgxZD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
PROTOFLOW_REGION:eyJpZCI6ImY2OTY3NzNjLWM4YmYtNDVjZC1iZTc5LTdjMmRmNWUwYzFlNSIsIm5hbWUiOiJIYXJ2YXJkIE1lbW9yeSAoUk9NL1JBTSkiLCJ4MSI6Njc1NC40OTYwMDAwMDAwMDEsInkxIjo2OTg4LjMzOTk5OTk5OTk5OSwieDIiOjc0MjUuNjgzOTk5OTk5OTk5LCJ5MiI6NzQ4NS4wNiwiY29sb3IiOjQyODU1MDc4MDQsImRlc2NyaXB0aW9uIjpudWxsLCJjb21wb25lbnRJZH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
PROTOFLOW_REGION:eyJpZCI6ImFiNGUxNzU2LTkzOGMtNDU0MC05YmQwLWI2NzUyY2IxY2RjOSIsIm5hbWUiOiJBTFUgJiBBY2N1bXVsYXRvciIsIngxIjowLjAsInkxIjo0OTMuNTYwMDAwMDAwMDAwMDYsIngyIjo2ODgzLjk0LCJ5MiI6MTIwMy42NDAwMDAwMDAwMDAzLCJjb2xvciI6NDI4NTUwNzgwNCwiZGVzY3JpcHRpb24iOm51bGwsImNvbXBvbmVudElkcyI6WyIzMzY0MzM0Mi0zYjIzLT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
PROTOFLOW_REGION:eyJpZCI6Ijg2ODFlY2MxLTRjMzYtNGRlZC04YjliLWI3MTBjMTIyYTljNCIsIm5hbWUiOiJBTFUgJiBBY2N1bXVsYXRvciIsIngxIjo0MDIzLjg3OTI0NDI1MDMxOCwieTEiOjMwODIuMzA4NzM3MDgwMDA5NSwieDIiOjUyMjAuMDg2NzkyNjI0OTQ3LCJ5MiI6Mzk0Mi45NDg1NDM4MTk5OTcsImNvbG9yIjo0Mjg1NTA3ODA0LCJkZXNjcmlwdGlvbiI6bnVsbCwiY29tcG9uZW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
PROTOFLOW_REGION:eyJpZCI6IjVhOTA0ZGEzLTVlMGYtNDUyNS1hZDU1LTBmODg0NTQzZTlmYSIsIm5hbWUiOiJSZWdpc3RlciBGaWxlIChSMC1SMykiLCJ4MSI6MTA4NjIuNTYwMDY3ODM5Nzk1LCJ5MSI6Mzg0OS44NDAyNTQzOTkyMzYsIngyIjoxMTUzMi4wMzk1OTI5NjEyMTksInkyIjo0Mjg5LjE1OTk1NzYwMDEyNiwiY29sb3IiOjQyODU1MDc4MDQsImRlc2NyaXB0aW9uIjpudWxsLCJjb2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
PROTOFLOW_REGION:eyJpZCI6IjUzZDJhODUyLTQwOGItNDI2Yi1iODI4LTU2YmYwMDEwYTkwYSIsIm5hbWUiOiJQQyAmIE1BUiIsIngxIjoyODUwLjUzNTk5OTk5OTk5OSwieTEiOjU0OTcuMzYwMDAwMDAwMDAxLCJ4MiI6MzYwOC4zODQsInkyIjo1ODUxLjg0LCJjb2xvciI6NDI4NTUwNzgwNCwiZGVzY3JpcHRpb24iOm51bGwsImNvbXBvbmVudElkcyI6WyJkYzkwNTlmOS1kYWRlLTQ4YmEtOD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
PROTOFLOW_REGION:eyJpZCI6IjVmZGYwMzkxLTJiYTUtNGVlZS1iZWNjLTQxZjgwY2MxOGJiZiIsIm5hbWUiOiJBTFUgJiBBY2N1bXVsYXRvciIsIngxIjo1Nzg2LjA1OTk5OTk5OTk5OTUsInkxIjoxMjA3LjMsIngyIjo5MDYwLjI0LCJ5MiI6MzA1NS4yOTk5OTk5OTk5OTkzLCJjb2xvciI6NDI4NTUwNzgwNCwiZGVzY3JpcHRpb24iOm51bGwsImNvbXBvbmVudElkcyI6WyIzN2VmNzM1Yi1mNz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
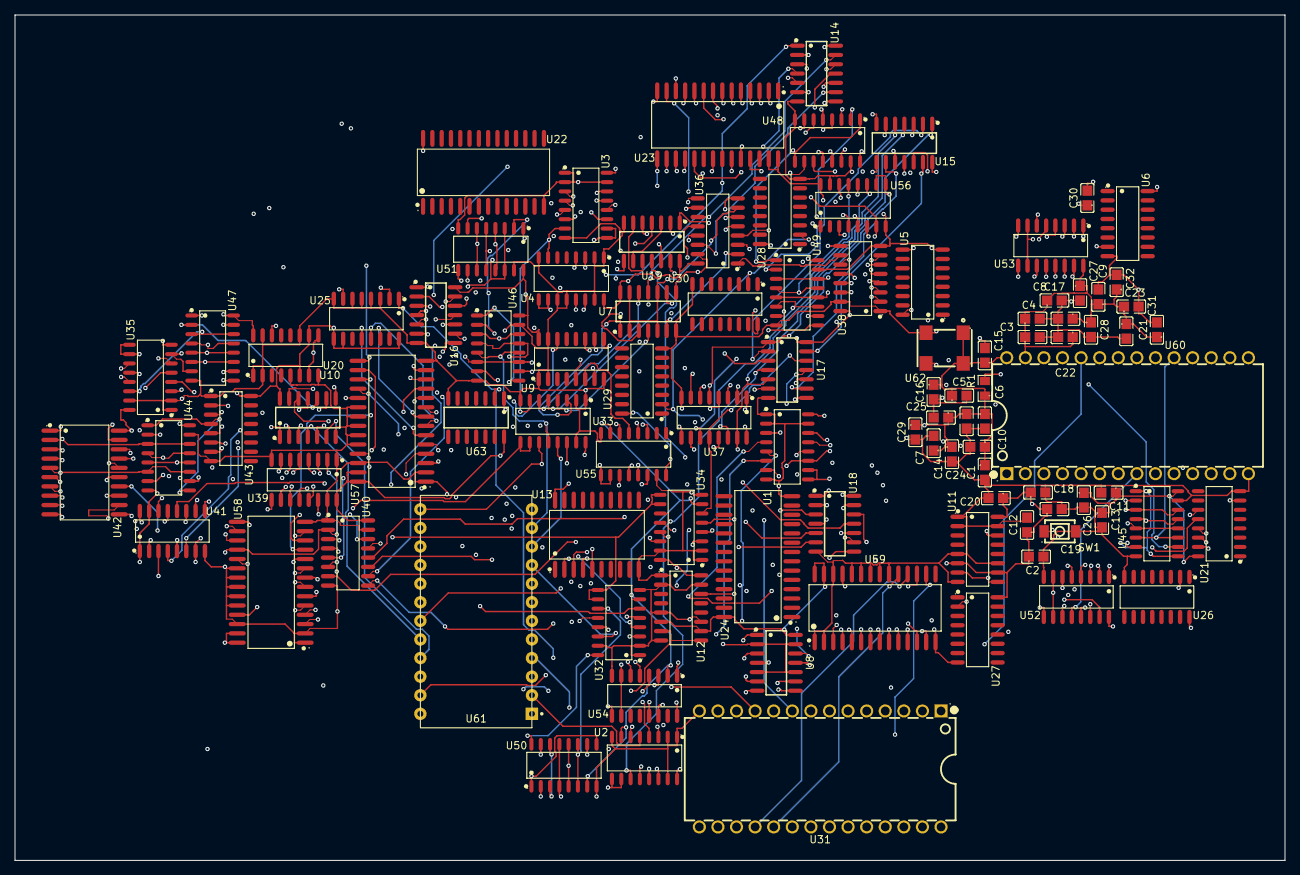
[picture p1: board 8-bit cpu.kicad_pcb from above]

Board: 4 copper layers, 173.5 x 115.5 mm, 97 parts (0 on the bottom side), 178 nets.
